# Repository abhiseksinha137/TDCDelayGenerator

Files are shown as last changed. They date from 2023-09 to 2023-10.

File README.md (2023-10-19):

# TDCDelayGenerator

This set of programs are used to control a VMI (Velocity Map Imaging) experiment.
## The Experiment

 Two optical elements are used in the experiment.
 1. An SPP (Spiral Phase Plate)
 2. A QWP (QWP)
 **Data Acquisition:**
 3. The TOF and position data from MCP are collected from a TDC in the form of a list mode file (lmf).

## Problem Statement
At each position of the SPP and QWP, the TDC data is acquired for an extended period of time (2-3 hours). Small changes in the laser beam due to changes in power or minute alignment changes can effect the individual runs leading to artifacts in the acquired data.

## Solution

 - The data will be acquired at each position for small duration (~ 3-5 min) for several runs. 
 - The same TDC acquisition file (lmf) will continue throughout the runs. 
 - A delay channel in the TDC is dedicated to distinguish the different parameters of the runs.
 
##  The Circuit
Delay Generator Chip **DS1023-25**
Stepper Motor Chip  **A4988**
A servo motor.
Piezo Rotation Stage :[ **CONEX-AG-PR100P**](https://www.newport.com/f/agilis-piezo-rotation-stages-with-conex-controller)
The circuit is detailed in the directory *./Circuit Details/*

## Circuit Control 
The various components of the circuit are controlled using a microcontroller (Arduino Nano) except for the piezo stage. 
The Arduino Nano code is in the directory *./Nanosecond_Delay_Generator_Circuit_Arduino_Code/delayGen5/delayGen5/*

## Overlord Code
A C# windows forms script is used to control all the elements (circuit elements via arduino) and conducting the Experiment.

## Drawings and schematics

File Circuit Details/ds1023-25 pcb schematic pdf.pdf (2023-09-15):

## DS1023S-25+

U1

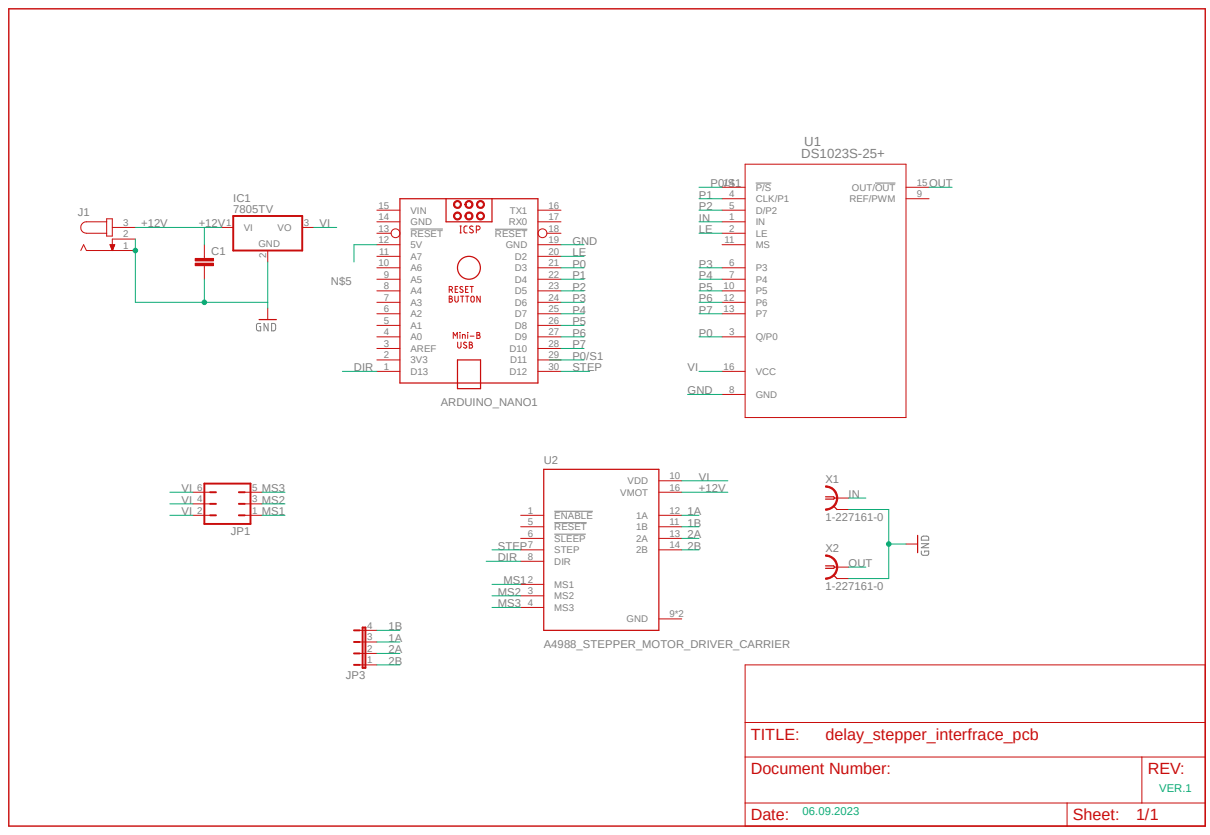
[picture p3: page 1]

Document Number: | REV: VER.1

Date: 06.09.2023 | Sheet: 1/1

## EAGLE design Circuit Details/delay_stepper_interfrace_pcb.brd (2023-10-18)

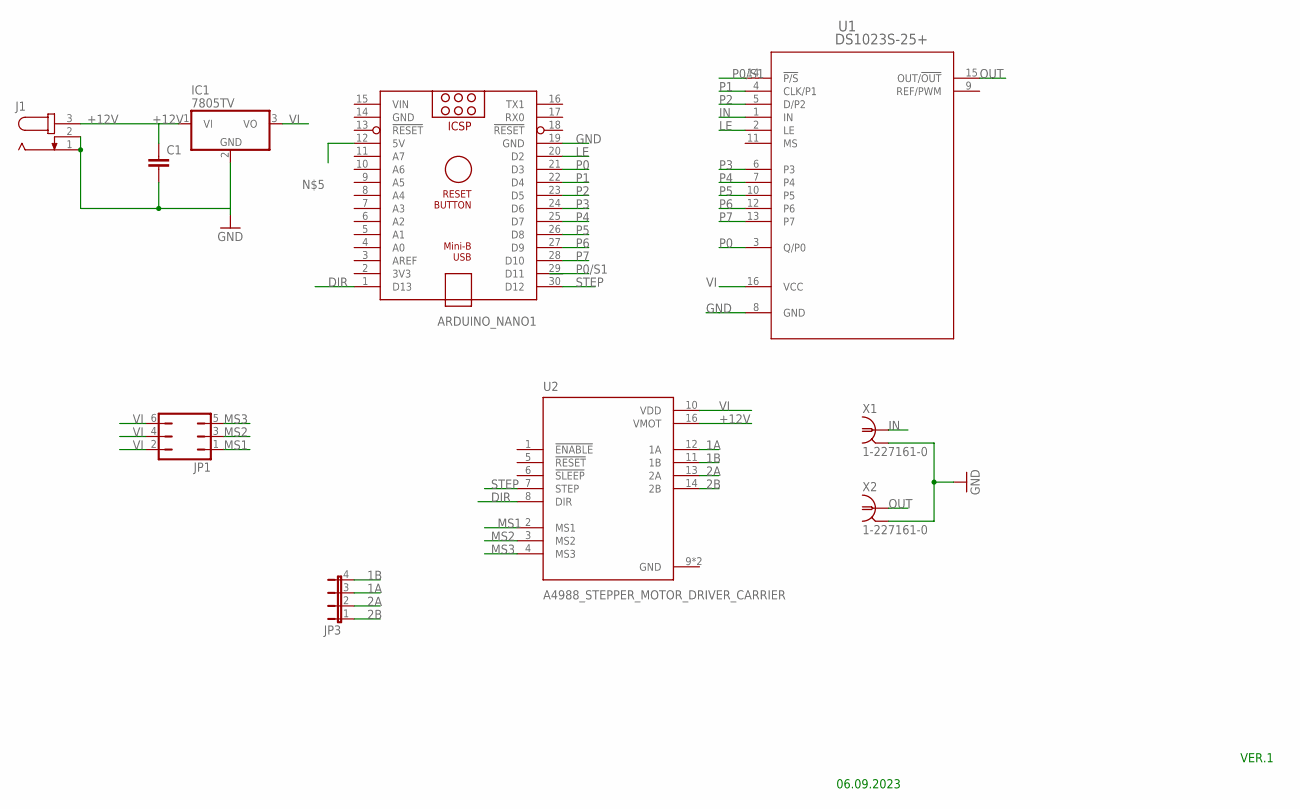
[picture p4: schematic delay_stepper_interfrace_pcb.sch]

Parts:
ARDUINO_NANO1: ARDUINO_NANO
C1: C2,5-3; C2.5-3
IC1: 7805TV; TO220V
J1: JACK-PLUG0; SPC4077
JP1: JP3Q
JP3: JP4E; JP4
U1: DS1023S-25+; 21-0042_AA_ADI
U2: A4988_STEPPER_MOTOR_DRIVER_CARRIER; MODULE_A4988_STEPPER_MOTOR_DRIVER_CARRIER
X1, X2: 1-227161-0; AMP_227161

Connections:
1A: JP3.3, U2.12 (1A)
1B: JP3.4, U2.11 (1B)
2A: JP3.2, U2.13 (2A)
2B: JP3.1, U2.14 (2B)
+12V: C1.1, IC1.1 (VI), J1.3, U2.16 (VMOT)
DIR: ARDUINO_NANO1.1 (D13), U2.8 (DIR)
GND: ARDUINO_NANO1.14 (GND), ARDUINO_NANO1.19 (GND), C1.2, IC1.2 (GND), J1.1, J1.2, U1.8 (GND), U2.9 (GND), U2.15 (GND), X1.2, X2.2
IN: U1.1 (IN), X1.1
LE: ARDUINO_NANO1.20 (D2), U1.2 (LE)
MS1: JP1.1, U2.2 (MS1)
MS2: JP1.3, U2.3 (MS2)
MS3: JP1.5, U2.4 (MS3)
OUT: U1.15 (OUT/!OUT), X2.1
P0: ARDUINO_NANO1.21 (D3), U1.3 (Q/P0)
P0/S1: ARDUINO_NANO1.29 (D11), U1.14 (!P/S)
P1: ARDUINO_NANO1.22 (D4), U1.4 (CLK/P1)
P2: ARDUINO_NANO1.23 (D5), U1.5 (D/P2)
P3: ARDUINO_NANO1.24 (D6), U1.6 (P3)
P4: ARDUINO_NANO1.25 (D7), U1.7 (P4)
P5: ARDUINO_NANO1.26 (D8), U1.10 (P5)
P6: ARDUINO_NANO1.27 (D9), U1.12 (P6)
P7: ARDUINO_NANO1.28 (D10), U1.13 (P7)
STEP: ARDUINO_NANO1.30 (D12), U2.7 (STEP)
VI: IC1.3 (VO), JP1.2, JP1.4, JP1.6, U1.16 (VCC), U2.10 (VDD)
VIN: ARDUINO_NANO1.15 (VIN)

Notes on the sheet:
06.09.2023
VER.1

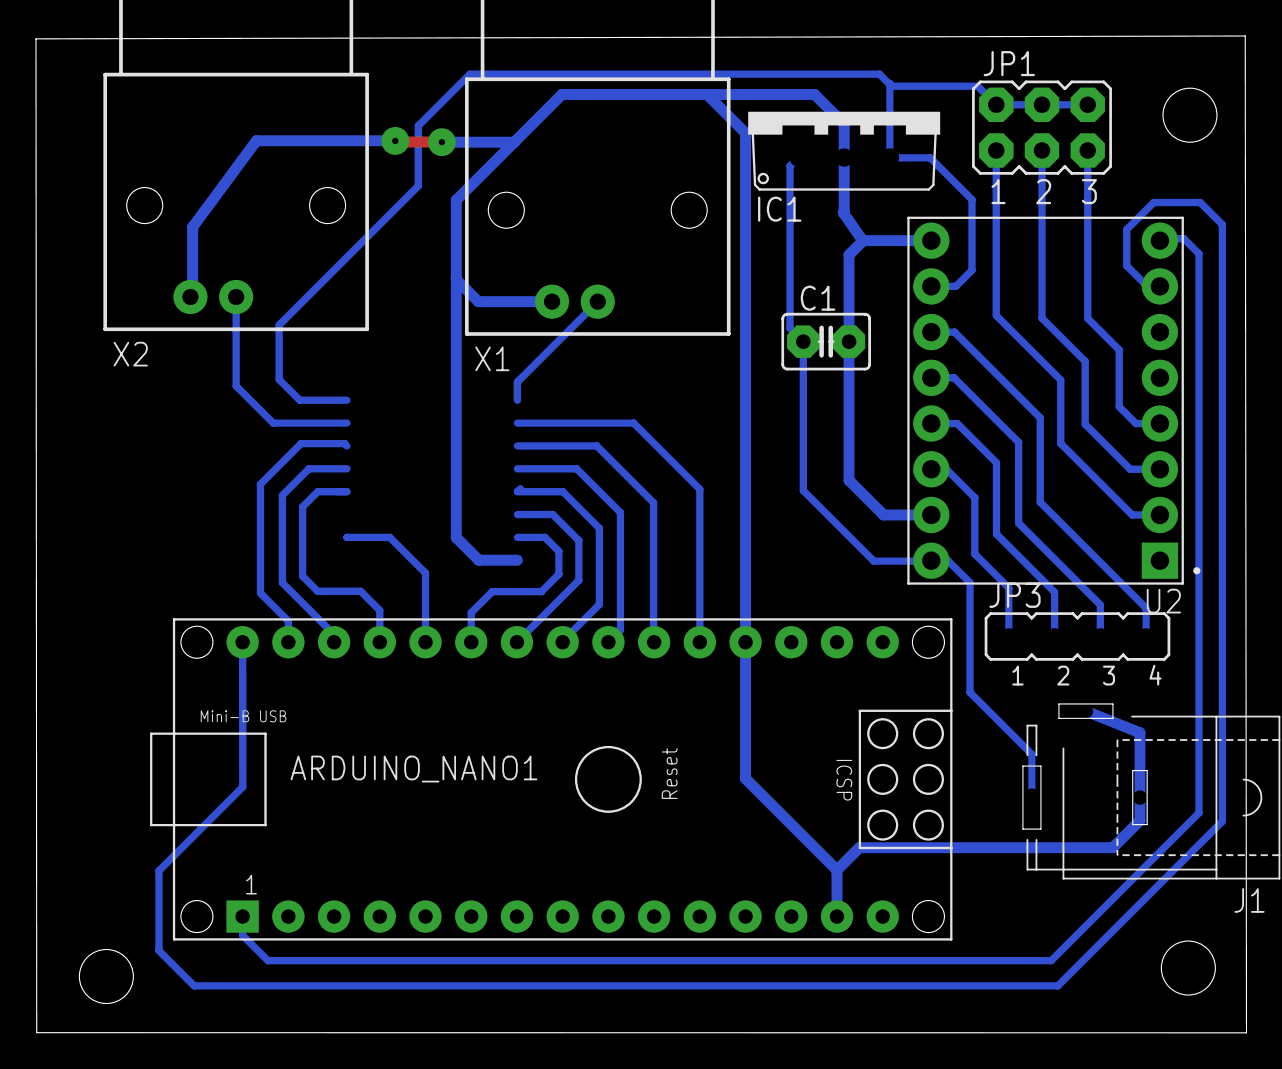
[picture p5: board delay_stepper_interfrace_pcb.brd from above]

Board: 2 copper layers, 67.2 x 55.4 mm, 10 parts (1 on the bottom side), 24 nets.

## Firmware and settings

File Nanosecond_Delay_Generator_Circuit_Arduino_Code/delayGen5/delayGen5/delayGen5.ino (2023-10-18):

#include <EEPROM.h>
#include <Servo.h>


// Input is of the form [r,s,d][0-9]
// r = rotation stage
// s = servo
// d = delay

// Define the output pins
const int outputPins[] = {3, 4, 5, 6, 7, 8, 9, 10};
const int numPins = sizeof(outputPins) / sizeof(outputPins[0]);

int commandReceived=0;

// Motor Params
#define dirPin 13
#define stepPin 12
int dly=1000; // delay in microseconds
int delayVal=0;
int servoPos=0;
//#define endPin 11

// Servo Params
Servo myservo; 
int servoPin=A5;

void donateDelay(int);

void setup() {
  Serial.begin(9600); // Initialize Serial communication
  // Initialize stepper pins
   pinMode(stepPin, OUTPUT);
   pinMode(dirPin, OUTPUT);

  // Initialize the output pins of delay chip
  for (int i = 0; i < numPins; i++) {
    pinMode(outputPins[i], OUTPUT);
  }

  // Initialize servo
  myservo.attach(servoPin);

  // Initiate Delay
  donateDelay();
}

void loop() {
  digitalWrite (2 ,HIGH); // Enable pin of stepper
  // Prompt the user for input
  //Serial.println("Enter an 8-bit number (0-255):");
  commandReceived=0;
  while (!Serial.available()) {
    // Wait for user input
    commandReceived=1;
  }
  

  String inputStr = Serial.readString();
  if (commandReceived==1)
  {
    delay(300);
    Serial.print("com"+inputStr);
  }  
  char firstChar=inputStr.charAt(0);
  //Serial.println(firstChar);

  if (firstChar=='r')
  { // Rotation Code
    //Serial.println("Rotation");
    String rotStr=inputStr.substring(1);
    if (isValidInput(rotStr))
    { 
      long rotVal=rotStr.toInt();
      rotateStage(rotVal);
    }

  }
  if (firstChar=='d')
  { // Delay Code
    //Serial.println("Delay");
    String delayStr=inputStr.substring(1);
    if (isValidInput(delayStr))
    {
      delayVal=delayStr.toInt();
  //    Serial.println(delayStr);
      donateDelay();
    }
  }
  if (firstChar=='s')
  { // Servo Code
    // Serial.println("Servo");
    String servoStr=inputStr.substring(1);
    
    if (isValidInput(servoStr))
    {
      servoPos=servoStr.toInt();
      servo();
    }
  }

   if (firstChar=='t')//tare
   {
     writeStagePos(0, 0);
     updateStatus();
   }
   if (firstChar=='p')//reply with current pos of rotation stage;
   {
    //  long currentPos=readStagePos(0);
    //  Serial.println(currentPos);
      updateStatus();
   }
//  int inputValue = Serial.parseInt(); // Read the user input as an integer


  
//  if (inputValue >= 0 && inputValue <= 255) {
//    // Update the output pins based on the binary representation of the input value
//    for (int i = 0; i < numPins; i++) {
//      digitalWrite(outputPins[i], (inputValue >> i) & 1);
//    }
//    
//    // Display the binary equivalent
//    Serial.print("Binary Equivalent: ");
//    for (int i = 7; i >= 0; i--) {
//      Serial.print((inputValue >> i) & 1);
//    }
//    Serial.println();
//    
//    Serial.print("Output set to: ");
//    Serial.println(inputValue);
//  } else {
//    Serial.println("Invalid input. Enter a number between 0 and 255.");
//  }
//  
//  // Clear the Serial buffer
//  while (Serial.available()) {
//    Serial.read();
//  }
}






void rotateStage(long target)
{
  long currentPos=readStagePos(0);
  long mov=target-currentPos;
  if (mov  > 0){
         
         for(int i=0; i<mov;i++){
           digitalWrite(dirPin, HIGH);
           digitalWrite(stepPin, HIGH);
           delayMicroseconds(dly);
           digitalWrite(stepPin, LOW);
           delayMicroseconds(dly);
         }
         currentPos=readStagePos(0)+mov;
         writeStagePos(0, currentPos);
      }
      if (mov  < 0){
         mov=-mov;
         for(int i=0; i<mov; i++){
           digitalWrite(dirPin, LOW);
           digitalWrite(stepPin, HIGH);
           delayMicroseconds(dly);
           digitalWrite(stepPin, LOW);
           delayMicroseconds(dly);
         }
         currentPos=readStagePos(0)-mov;
         writeStagePos(0, currentPos);
      }
  // currentPos=readStagePos(0);
  // Serial.println(currentPos);
  updateStatus();
}

void donateDelay()
{
  int inputValue=delayVal;
  if (inputValue >= 0 && inputValue <= 255) {
      // Update the output pins based on the binary representation of the input value
      for (int i = 0; i < numPins; i++) {
        digitalWrite(outputPins[i], (inputValue >> i) & 1);
      }
      
      // Display the binary equivalent
//      Serial.print("Binary Equivalent: ");
//      for (int i = 7; i >= 0; i--) {
//        Serial.print((inputValue >> i) & 1);
//      }

      }
  updateStatus();
}


void servo()
{
    myservo.write(servoPos);
    updateStatus();
}


void writeStagePos(int addrOffset, long pos )
{
  String strToWrite=String(pos) ;
  
  byte len = strToWrite.length();
  EEPROM.write(addrOffset, len);
  for (int i = 0; i < len; i++)
  {
    EEPROM.write(addrOffset + 1 + i, strToWrite[i]);
  }
}

long readStagePos(int addrOffset)
{
  int newStrLen = EEPROM.read(addrOffset);
  char data[newStrLen + 1];
  for (int i = 0; i < newStrLen; i++)
  {
    data[i] = EEPROM.read(addrOffset + 1 + i);
  }
  data[newStrLen] = '\ 0'; // !!! NOTE !!! Remove the space between the slash "/" and "0" (I've added a space because otherwise there is a display bug)
  String retStr=String(data);
  long ret=retStr.toInt();
  return ret/10;
}

void updateStatus(){
  Serial.println(String(readStagePos(0))+","+String(delayVal)+","+String(servoPos));
}

int isValidInput(String input)
{
  int str_len=input.length();
  char inputChar[str_len];
  input.toCharArray(inputChar, str_len);
  // Serial.println(inputChar);
  for(int i =0; i < str_len-1; i++ ) 
  {
    
    char c = inputChar[i];
    if (!isDigit(c))  // tests if myChar is a digit
    {
      // Serial.println(c);
      // Serial.println("Not a Number");
      return 0;
    }
    else{
      // Serial.print("Number ");
      // Serial.println(c);
    }
  }
  return 1;
}

//s0/1
//r0-359
//d0-255

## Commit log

2023-09-18 Added arduino code for delay value response. C# code updated.
2023-10-17 Added delayGen5.ino; syncrhonised stage motion using AutoResetEvent
2023-10-18 Changes in Arduino
    [delay_stepper_interfrace_pcb.brd, delay_stepper_interfrace_pcb.sch]
2023-10-18 Working + Arduino Changes

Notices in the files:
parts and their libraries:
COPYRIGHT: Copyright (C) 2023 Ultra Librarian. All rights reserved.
